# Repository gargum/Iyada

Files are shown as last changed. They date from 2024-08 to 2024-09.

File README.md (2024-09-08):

# Iyada

Iyada

*The Iyada is a keyboard, mouse, space mouse, and a gamepad in one unit*

* Keyboard Maintainer: [Gareth Gummow](https://github.com/gargum)
* Demonstration: [Iyada Dual Analogue Gameplay](https://imgur.com/gallery/iyada-simple-demos-vVryoOj)
* Recommended Keycaps: [KLP Lamé](https://github.com/braindefender/KLP-Lame-Keycaps)

This device is powered by QMK Firmware running on two RP2040 Microcontrollers.

To flash the firmware for it, simply copy the kiraibuilds/iyada directory to the ~/qmk_firmware/keyboards locally on your machine before following one of the make examples included in the appropriate Readme file.

To learn how to set up QMK locally on your machine, see the [build environment setup](https://docs.qmk.fm/#/getting_started_build_tools) and the [make instructions](https://docs.qmk.fm/#/getting_started_make_guide). 

Brand new to QMK? Start with the [Complete Newbs Guide](https://docs.qmk.fm/#/newbs)

## Features

* **Simultaneous Choc/MX Hotswap Compatibility**: The Iyada is simultaneously MX and Choc hotswap compatible. This means one can use any combination of Choc and MX switches or switch between them without having to reflash the firmware!
* **OLED Screens**: The Iyada is equipped with a 32x128 OLED screenn on each side. The lefthand OLED tells the user which layer is currently active, and the righthand OLED displays a fun, unobtrusive animation!
* **Four Encoders**: The Iyada is equipped with a rotary encoder and a scroll encoder on each side of the keyboard! By default, these are used for the purposes of web navigation and media playback.
* **Dual Pointers**: The Iyada is equipped with a Cirque Pinnacle trackpad on each side! By default, these can be used for mouse cursor movement. However, they are also configured to function as dual analogue sticks in video games!
* **RGB Lighting**: The baseplate of the Iyada comes equipped with LEDs, allowing for RGB animations and simple backlighting should the user so desire!
* **Haptic Feedback**: The Iyada is equipped with a DRV2605L on each half, allowing for haptic feedback that informs the user that a layer shift key has been pressed!
* **Audio Feedback**: The Iyada is equipeed with a small piezoelectric speaker on each side that relies on hardware-driven PWM to produce sound! By default, this allows the user to make the Iyada produce an audible sound whenever a key is pressed.
* **Power Boosting**: The Iyada is equipped with a TP4056 and a lithium polymer battery on each side! This allows one to provide extra power, thereby ensuring features like RGB and Haptics are always working as expected, no matter the configuration!
* **Advanced Autocorrect**: QMK includes the ability to define custom dictionaries for use with the [Autocorrect feature](https://docs.qmk.fm/features/autocorrect). As part of the Iyada project, the largest ever such dictionary has been created, compiled, and added for use with this, or any other piece of hardware that utilises QMK firmware!
* **Dual Analogue Support**: The Iyada natively supports virtual dual analogue sticks. This means, using software such as a video game emulator, one is able to map each Cirque Pinnacle trackpad to its own
separate analogue stick. The first version of full Cirque joystick emulation has already been implemented and is ready for use. Fully polished digital joystick emulation is still production!

## Additional Information

* **Cirque Sizing**: Although 40mm Cirque trackpads are recommended, one may use any size that one so desires. 40mm Cirque trackpads are used only because they are popularly considered to be the most comfortable variety. The only issue associated with using a smaller Cirque is that it may not be possible to attach these Cirques to the Iyada Cirque holders perfectly centred.
* **Cirque Holder**: UV resin is used to attach a Cirque to the Iyada Cirque holder. All 40mm Cirques have been confirmed to be able to attach to the standard Cirque holder regardless of the type of overlay it comes with. To attach a Cirque to the Iyada Cirque holder, it is recommended that one first attaches the Cirque holder to the Iyada top PCB using a heat-set insert and M2.2 screw, then connects the Cirque to the Iyada top PCB, before using something like hot glue or tape to test what position and orientation is most comfortable for use. After one is happy with the position and orientation, and after one is sure the Cirque has been connected to the Iyada top PCB properly, a very small amount of UV resin can then be used to permanently secure the trackpad to its holder. After this, the hot glue or tape may be removed. 
* **Curved Overlay**: All features including secondary click functions and scrolling functions work with the curved overlay, however the attenuation in config.h must be set to its maximum value of 1 for this to work consistently. It does still technically work if the attenuation is set to a value of 2, but in testing was reported as being frustrating to use.
* **Cirque Attenuation**: If one is not using the curved overlay, setting the attenuation in config.h to 3 or 4 generally works best. If one does have curved overlays on one's Cirque trackpads, then setting the attenuation to 1 or 2 generally works best.
* **Cirque Positioning**: It is recommended to mount each Cirque trackpad to the keyboard such that it is angled away from the MCU by an angle of between 20 degrees and 40 degrees. Mounting the Cirques perfectly straight tends to make it more difficult for one to use one's thumbs to control mouse pointing.
* **Cirque Conflicts**: It is worth noting that using the Steno and/or Joystick functionality may cause the Cirques to become less accurate, more prone to drifting, and overall more painful to use.
* **Cirque Problems**: If a Cirque trackpad is only partially connected, then the mouse pointer should jitter erratically when one attempts to use it. If SDA or SCL are not connected properly at all, then the Cirque trackpad will only be able to move in the X direction or in the Y direction but not both. If there is jittering in the X direction but not the Y direction, or vice versa, then either SDA or SCL is partially connected while the other is fully connected. If the Cirque drops user input periodically when the attenuation is set to 1, almost like stuttering or lagging, then 5V or GND are not properly connected. If the Cirque does not respond at all despite the correct solder jumpers being closed, then either that half is not receiving sufficient power, or the Cirque is not properly connected. To resolve every single one of these problems, use 3.3V Cirques, reconnect/resolder the Cirques, add the battery/charging accessories, and use either WS2812B-2020 LEDs or no LEDs at all before testing again. In case one simply removes a pad or trace by accident while adding a Cirque trackpad, each half of the keyboard has 3 places where it is possible to solder a Cirque alongside 2 places where an FPC connecter for a Cirque can be added. If none of this works, disconnect any LEDs and try using the Cirque. If it suddenly works fine, the problem was insufficient power. If nothing changes, the problem is the connection between the Cirque and the PCB.
* **Haptic Compatibility**: The Iyada is designed to support all haptic feedback drivers that are compatible with QMK. By default, it is configured to use the DRV2605L, however the Iyada is also natively compatible with solenoid drivers if one would prefer to use that instead.
* **Audio**: The Iyada natively supports the use of piezo speakers for the purposes of audio feedback. Simply hand-wire one's speaker to the appropriately on each half of the Iyada in order to utilise this feature.
* **SPI Peripherals**: The Iyada supports direct control of SPI-based peripherals, including Cirque trackpads that have been configured to communicate via SPI. If one wants to use any such peripheral, simply hand-wire the appropriate connections the corresponding 4 pins located on the bottom of the MCU.
* **Power Draw**: If one uses two 5V Cirque trackpads in tandem with WS2812B-5050 LEDs, the battery and charging accessories are required to provide all components with sufficient power simultaneously. Neglecting to do so when using this configuration will result in the 5V Cirque present on the secondary half of the keyboard to become non-responsive. Even with the additional battery and charging accessories, it is possible that there will still be insufficient power if one is using an Iyada with two 5V Cirque trackpads, WS2812B-5050 LEDs, and additional non-standard peripherals connected via an SPI to I2C bus-bridge such as the SC18IS604.
* **Battery Connections**: The Iyada natively supports the use of a lipo battery on each half to help power more energy-intensive configurations. Simply solder the battery wires to the TP4056 units on each half, and position the battery so as to not block any of the Iyada's LEDs.

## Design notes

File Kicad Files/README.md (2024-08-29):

# Iyada PCB

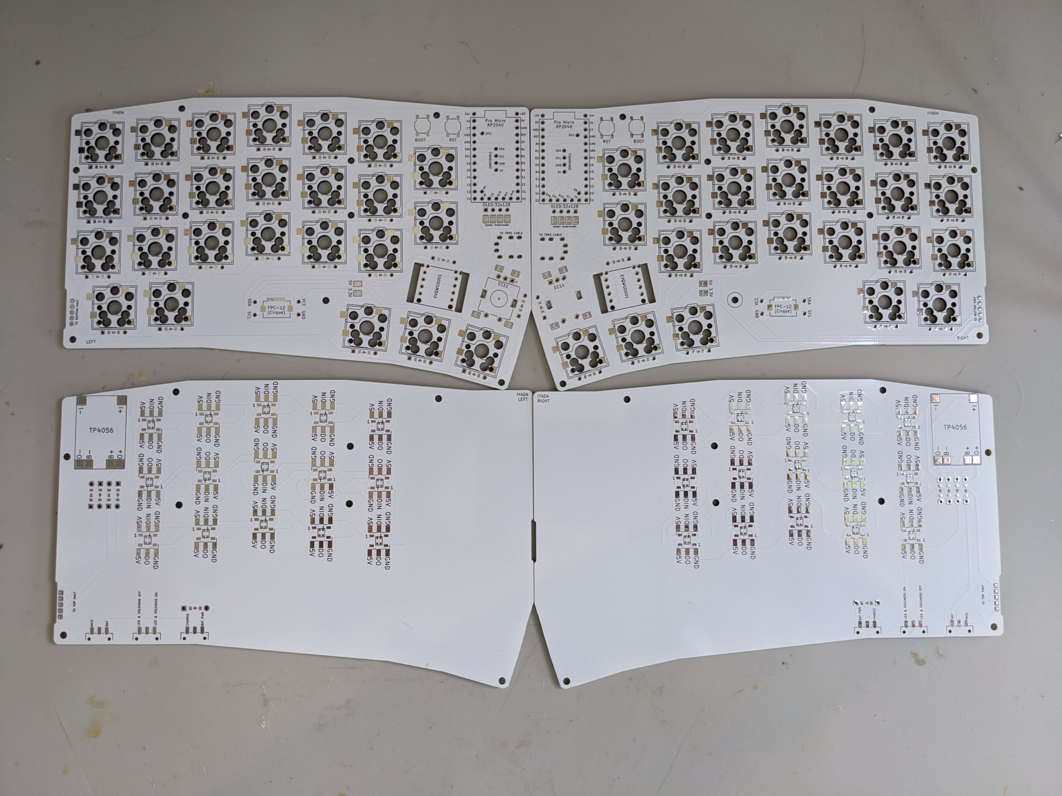
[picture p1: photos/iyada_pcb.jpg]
Iyada


*The Iyada comes in four parts - Top Left, Bottom Left, Top Right, and Bottom Right*

All PCBs used are reversible. This means a bottom PCB will function as both a bottom left and as a bottom right half, while a top PCB will function as both a top left and top right half.

## PCB Fabrication

The iyada_top and iyada_bottom directories each contain a .zip file, iyada_top.zip and iyada_bottom.zip respectively.

To fabricate the Iyada, simply take these .zip files, go to a website such as [JLCPCB](jlcpcb.com/) or [PCBWay](pcbway.com/), and upload them when prompted to provide a gerber file.

## Features

* **Reversible PCBs**: As previously mentioned, all PCBs are reversible, so only the top PCB functions as the top half of both sides, and the bottom PCB functions as the bottom half of both sides.
* **Simultaneous Choc & MX Hotswap Support**: Each key simultaneously accomodates Choc and MX hotswaps. This is to allow every key to accept a low-profile Choc switch, or a standard MX switch, without the need to resolder anything or reflash any firmware.
* **Two Rotary Encoders**: Each top PCB has a reversible slot for either an EC11 or EC12 rotary encoder, complete with intact click functionality!
* **Two Scroll Encoders**: Each top PCB has a reversible slot for a EVQWGD001 scroll encoder, also complete with intact click functionality!
* **Support for Multiple Sizes of LED**: The bottom PCB is designed to accomodate WS2812 RGB LEDs in multiple sizes, including WS2812 RGB LEDs cut from RGB LED strips!
* **TP4056 Slot**: Features like large LEDs and haptic feedback can take quite a lot of power. That's why the bottom PCB has a dedicated slot for a TP4056, which is used to safely provide more than enough additional electricity!

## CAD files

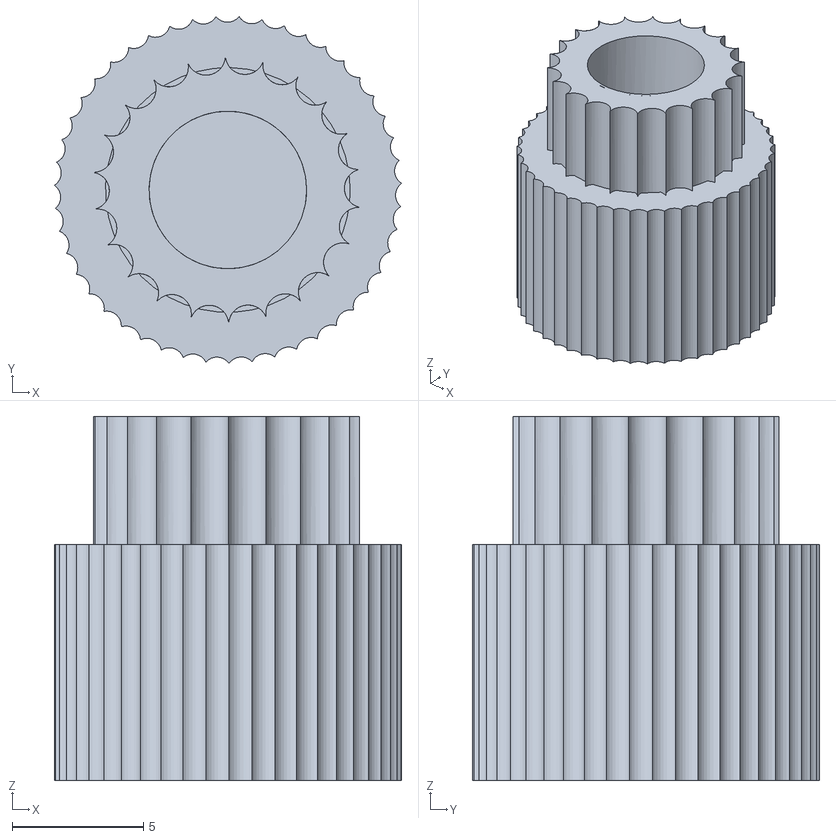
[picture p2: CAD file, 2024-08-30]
3D Print Files/Iyada - Encoder Knob - EC12.stl
13.2 x 13.2 x 13.9

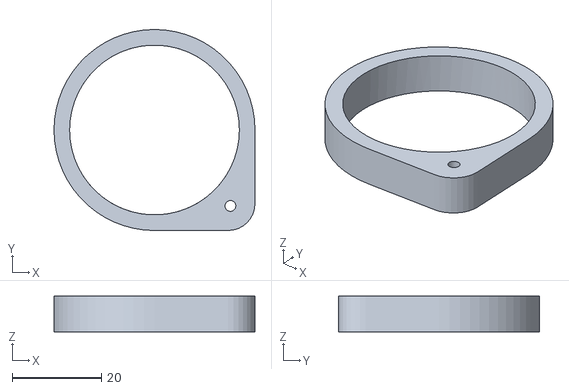
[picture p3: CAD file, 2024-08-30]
3D Print Files/Iyada - Cirque Holder.stl
45.0 x 45.0 x 8.00

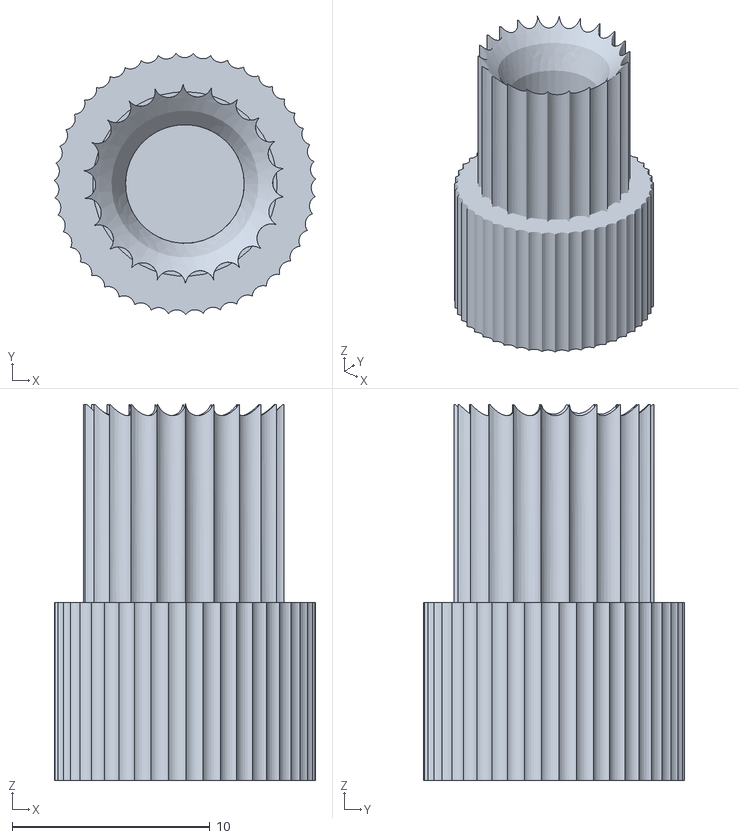
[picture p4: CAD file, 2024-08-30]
3D Print Files/Iyada - Encoder Knob - EC11.stl
13.2 x 13.2 x 19.0

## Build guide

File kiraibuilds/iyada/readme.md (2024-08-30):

# Iyada

Iyada (https://i.imgur.com/hbfquj2.mp4)

*The Iyada is a keyboard, mouse, space mouse, and a gamepad in one unit*

* Keyboard Maintainer: [Gareth Gummow](https://github.com/gargum)
* Hardware Supported: *2 Iyada top PCBs, 2 Iyada bottom PCBs, 2 Iyada base plates, 2 Iyada mounting rings, 2 Iyada Cirque holders, 2 RP2040 Pro Micro microcontrollers, 2 EC12 low profile rotary encoders, 2 EVQWGD001 scroll encoders, 2 OLEDs (32x128), 2 Cirque Pinnacle trackpads (40mm / TM040040 is recommended), 2 FPC 12-pin cables, 2 FPC reverse side solder-mount connectors, 100 Hotswap sockets (50 Choc & 50 MX, or 50 Choc & 50 Gateron), 30 WS2812B LEDs (WS2812B-2020 is recommended), 2 DRV2605L haptic drivers, 2 Haptic motors, 2 TP4056 lipo chargers, 2 lipo batteries, 6 SPDT switches, 2 TRRS connectors, 1 TRRS cable, 62 Diodes (62 1N4148 or 62 LL4148), 34 screws (M2.2), 2 heat-set inserts (M2.2), 16 M.2 SSD standoffs (All 16 must be the same height), Wires (30 Gauge), Solder (paste and/or wire), UV resin or hot glue or double-sided tape*
* Hardware Availability: [AliExpress](https://aliexpress.com), [Mouser](https://mouser.com), [DigiKey](https://digikey.com), [JLCPCB](https://jlcpcb.com), [PCBWay](https://pcbway.com)

Make example for this keyboard (after setting up your build environment):

    make kiraibuilds/iyada:default

Alternative make example for this keyboard using QMK:

    qmk compile -kb kiraibuilds/iyada -km joystick

Flashing example for this keyboard using QMK:

    qmk flash -kb kiraibuilds/iyada -km advanced

See the [build environment setup](https://docs.qmk.fm/#/getting_started_build_tools) and the [make instructions](https://docs.qmk.fm/#/getting_started_make_guide) for more information. 

Brand new to QMK? Start with the [Complete Newbs Guide](https://docs.qmk.fm/#/newbs)

## Bootloader

One can enter the bootloader of each keyboard half separately if one so chooses. This is necessary when flashing a newly constructed Iyada for the first time, and when one wishes to alter the default behaviours of the RGB LEDs.

One may also use a TRRS cable to connect both halves, before entering the bootloader on the master half alone. Flashing both halves simultaneously in this fashion is convenient when one is simply flashing a new keymap onto a pre-existing Iyada without making any other changes.

One is able to enter the bootloader in 5 ways:

* **Bootloader button**: First, unplug the Iyada from one's computer. Then, press and hold the button labelled 'Boot' on the front of the PCB, and keep it held down as one plugs the Iyada into the computer once more. This should cause the Iyada to enter the bootloader.
* **Reset button**: Simply double-tap the button labelled 'reset' on the front of the PCB. This should cause the Iyada to enter the bootloader.
* **Paperclip reset**: Take a screwdriver or paperclip, then use it to connect the RST and GND pins on the microcontroller. Please be careful, as one can accidentally short the MCU. By quickly doing this twice in a row, one is able to enter the bootloader using the reset button method without actually pressing the physical reset button.
* **Bootmagic reset**: Bootmagic is enabled by default. With Bootmagic, one can hold the top right key on the right half of the keyboard and plug it in. If using the left half by itself, or if holding the top right key on the right half of the board simply is not working, then instead hold the top left key on the left half of the keyboard.
* **Keycode in layout**: If one has included the keycode `QK_BOOT` somewhere in a custom keymap, then triggering it will enter the bootloader. This is unavailable on the default keymap.

## Additional Information

* **Cirque Sizing**: Although 40mm Cirque trackpads are recommended, one may use any size that one so desires. 40mm Cirque trackpads are used only because they are popularly considered to be the most comfortable variety. The only issue associated with using a smaller Cirque is that it may not be possible to attach these Cirques to the Iyada Cirque holders perfectly centred.
* **Cirque Holder**: UV resin is used to attach a Cirque to the Iyada Cirque holder. All 40mm Cirques have been confirmed to be able to attach to the standard Cirque holder regardless of the type of overlay it comes with. To attach a Cirque to the Iyada Cirque holder, it is recommended that one first attaches the Cirque holder to the Iyada top PCB using a heat-set insert and M2.2 screw, then connects the Cirque to the Iyada top PCB, before using something like hot glue or tape to test what position and orientation is most comfortable for use. After one is happy with the position and orientation, and after one is sure the Cirque has been connected to the Iyada top PCB properly, a very small amount of UV resin can then be used to permanently secure the trackpad to its holder. After this, the hot glue or tape may be removed. 
* **Curved Overlay**: All features including secondary click functions and scrolling functions work with the curved overlay, however the attenuation in config.h must be set to its maximum value of 1 for this to work consistently. It does still technically work if the attenuation is set to a value of 2, but in testing was reported as being frustrating to use.
* **Cirque Attenuation**: If one is not using the curved overlay, setting the attenuation in config.h to 3 or 4 generally works best. If one does have curved overlays on one's Cirque trackpads, then setting the attenuation to 1 or 2 generally works best.
* **Cirque Positioning**: It is recommended to mount each Cirque trackpad to the keyboard such that it is angled away from the MCU by an angle of between 20 degrees and 40 degrees. Mounting the Cirques perfectly straight tends to make it more difficult for one to use one's thumbs to control mouse pointing.
* **Cirque Conflicts**: It is worth noting that using the Steno and/or Joystick functionality may cause the Cirques to become less accurate, more prone to drifting, and overall more painful to use.
* **Cirque Problems**: If a Cirque trackpad is only partially connected, then the mouse pointer should jitter erratically when one attempts to use it. If SDA or SCL are not connected properly at all, then the Cirque trackpad will only be able to move in the X direction or in the Y direction but not both. If there is jittering in the X direction but not the Y direction, or vice versa, then either SDA or SCL is partially connected while the other is fully connected. If the Cirque drops user input periodically when the attenuation is set to 1, almost like stuttering or lagging, then 5V or GND are not properly connected. If the Cirque does not respond at all despite the correct solder jumpers being closed, then either that half is not receiving sufficient power, or the Cirque is not properly connected. To resolve every single one of these problems, use 3.3V Cirques, reconnect/resolder the Cirques, add the battery/charging accessories, and use either WS2812B-2020 LEDs or no LEDs at all before testing again. In case one simply removes a pad or trace by accident while adding a Cirque trackpad, each half of the keyboard has 3 places where it is possible to solder a Cirque alongside 2 places where an FPC connecter for a Cirque can be added. If none of this works, disconnect any LEDs and try using the Cirque. If it suddenly works fine, the problem was insufficient power. If nothing changes, the problem is the connection between the Cirque and the PCB.
* **Mounting Compatibility**: The internal tenting puck system is primarily for the purposes of attaching the Iyada to either a tripod, or of making it easier to secure the Iyada to an office chair. As the name implies, This also makes it possible to simply tent one's Iyada.
* **Haptic Compatibility**: The Iyada is designed to support all haptic feedback drivers that are compatible with QMK. By default, it is configured to use the DRV2605L, however the Iyada is also natively compatible with solenoid drivers if one would prefer to use that instead.
* **Audio**: The Iyada natively supports the use of piezo speakers for the purposes of audio feedback. Simply hand-wire one's speaker to the appropriately on each half of the Iyada in order to utilise this feature.
* **SPI Peripherals**: The Iyada supports direct control of SPI-based peripherals, including Cirque trackpads that have been configured to communicate via SPI. If one wants to use any such peripheral, simply hand-wire the appropriate connections the corresponding 4 pins located on the bottom of the MCU.
* **Power Draw**: If one uses two 5V Cirque trackpads in tandem with WS2812B-5050 LEDs, the battery and charging accessories are required to provide all components with sufficient power simultaneously. Neglecting to do so when using this configuration will result in the 5V Cirque present on the secondary half of the keyboard to become non-responsive. Even with the additional battery and charging accessories, it is possible that there will still be insufficient power if one is using an Iyada with two 5V Cirque trackpads, WS2812B-5050 LEDs, and additional non-standard peripherals connected via an SPI to I2C bus-bridge such as the SC18IS604.
* **Battery Connections**: The Iyada natively supports the use of a lipo battery on each half to help power more energy-intensive configurations. Simply solder the battery wires to the TP4056 units on each half, and position the battery so as to not block any of the Iyada's LEDs.
* **Dual Analogue Support**: The Iyada natively supports virtual dual analogue sticks. This means, using software such as a video game emulator, one is able to map each Cirque Pinnacle trackpad to its own
separate analogue stick for use in modern games. By default, flicking or swiping in a direction will toggle that direction, and tapping will reset it. This is to allow those with RSI or arthritis that prevents
one from holding down a standard analogue stick to use a dual analogue input method. As a side-effect, this method also frees up one's thumbs, better allowing one to use gamepad buttons mapped to the thumb cluster.

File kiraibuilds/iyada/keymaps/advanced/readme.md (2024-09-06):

# Advanced Iyada Layout - Introduction

The advanced layout exists to showcase as many of the existing features
of the Iyada as possible, while at the same time still remaining accessible
to those who are new to QMK. Learning this keymap should help beginners 
become acquainted with concepts including Layers, Combos, and Tap Dance, 
without being too confusing or overwhelming for novices.

Each half of the keyboard has a small OLED screen. These screens are 
there to provide information to the user regarding the current state of 
the keyboard, including which layer the keyboard is currently in, and even
whether problems with keyboard output are being caused by one's system being
unresponsive, or whether the problem is instead to do with the keyboard.

The primary layer, labelled 'main' on the secondary OLED display, outputs
letters using a standard QWERTY keymap.

The secondary layer, labelled 'symbol' on the secondary OLED display, allows
the user to press the Function keys F1-F12, the digits 0-9, and all shifted
variants of the ten digits such as the exclamation point and the dollar sign.
To enter this layer, simply press the corresponding Layer shift key located on
the lefthand thumb cluster.

The third layer, labelled 'mouse' on the secondary OLED display, allows the
user to control mouse movements, more easily reach arrow keys, and even change 
keyboard settings. Available settings on this layer include changing the behaviour 
of the LEDs, changing the behaviour of the haptic feedback module, and adjusting 
one's mouse sensitivity. To enter this settings layer, simply press the corresponding
Layer shift key located on the righthand thumb cluster.

On each half of the keyboard are a rotary encoder and a scroll encoder. 

On any layer, the lefthand rotary encoder can be turned to turn the system 
volume up or down. Pressing down on the lefthand rotary encoder will mute and 
unmute the system.

On any layer, the righthand rotary encoder can be turned to go to the next or
to the previous tab in Chromium-based web browsers like Chrome and Vivaldi. 
Pressing down on the righthand rotary encoder will pause or unpause media.

On any layer, the lefthand scroll encoder can be used to scroll up and down,
just as one would do with a standard mouse wheel. Pressing down on this 
scroll encoder will trigger the back button on any web browser, assisting
with web navigation.

On any layer, the righthand scroll encoder can be used to scroll side to side,
which may come in handy for some applications. Pressing down on this scroll
encoder will trigger the forward button on any web browser, again assisting
with web navigation.

Pressing both Layer shift keys simultaneously will toggle a fourth layer,
labelled 'Game' on the secondary OLED display. This layer transforms the
Iyada into a gamepad, with each Cirque Pinnacle trackpad functioning as
its own analogue stick and the face buttons also being remapped appropriately
to gamepad buttons.

On each layer, the six thumb keys, the leftmost column of three keys, and the
rightmost column of three keys will always be the same, although they are
deactivated when one is using the Game layer.

The lefthand cluster of three thumb keys, in order from left to right, 
correspond to Space, Backspace, and Symbols layer key. These keys function
normally with the exception of the Backspace key, which registers as a normal
Backspace key when tapped but outputs Ctrl+Backspace when held down.

The righthand cluster of three thumb keys, in order from left to right,
correspond to the Mouse layer toggle, Enter, and Shift respectively. No
special functions have been mapped to the Enter or Shift key. In this keymap,
Shift corresponds to the Left Shift key, and Right Shift is entirely absent.

The key on the outer bottom corners of each keyboard half are called Space
Cadet keys. When held, they correspond to the Ctrl key. When tapped, they
correspond to the left and right brackets, ( and ). 

The keys just above the Space Cadet keys function similarly. When held, they
correspond to the left and right Windows keys respectively. When tapped, the
lefthand key corresponds to the Delete key, when the righthand key outputs
the apostrophe key, with the appropriate behaviour when Shift is also held.

Finally, at the top left and top right corners of the keyboard are keys with
three different functions known as Tap Dance keys. 
When the topmost leftmost key is tapped, it outputs the Tab key.
When this key is held, it outputs the Left Alt key.
When this key is quickly double-tapped, it outputs the Escape key.

When the topmost rightmost key is tapped, it outputs a Backslash.
When this key is held, it outputs the Right Alt key.
When this key is quickly double-tapped, it outputs the Grave key.

This layout is recommended for those who have not previously owned a custom
mechanical keyboard, and for those who have not previously used a keyboard
that includes a built-in trackball or touchpad.

# Advanced Iyada Layout - Diagrams

<tt>

                                  MAIN LAYER

    ,---,---,---,---,---,---,                          ,---,---,---,---,---,---,
    |ESC| Q | W | E | R | T |---,                  ,---| Y | U | I | O | P | \ |
    '---'---'---'---'---'---| [ |                  | ] |---'---'---'---'---'---'
    |DEL| A | S | D | F | G '---'                  '---' H | J | K | L | ; | ' |
    '---'---'---'---'---'---| - |                  | = |---'---'---'---'---'---'
    |CTL| Z | X | C | V | B '---'                  '---' N | M | , | . | / |CTL|
    '---'---'---'---'---'---'                          '---'---'---'---'---'---'
      | V | < |            (EC1)(EC2)          (EC3)(EC4)            | > | ^ |
      '---'---'         ,---,---,---,          ,---,---,---,         '---'---'
                        |SPC|BCK|LSY|          |LMO|ENT|SFT|
                        '---'---'---'          '---'---'---'

                                     SYMBOL LAYER

    ,---,---,---,---,---,---,                          ,---,---,---,---,---,---,
    |ESC|F1 |F2 |F3 |F4 |F5 |---,                  ,---|F8 |F9 |F10|F11|F12| \ |
    '---'---'---'---'---'---|F6 |                  |F7 |---'---'---'---'---'---'
    |DEL| 1 | 2 | 3 | 4 | 5 '---'                  '---' 6 | 7 | 8 | 9 | 0 | ' |
    '---'---'---'---'---'---| - |                  | = |---'---'---'---'---'---'
    |CTL| ! | @ | # | $ | % '---'                  '---' ^ | & | * | . | ? |CTL|
    '---'---'---'---'---'---'                          '---'---'---'---'---'---'
      | V | < |            (EC1)(EC2)          (EC3)(EC4)            | > | ^ |
      '---'---'         ,---,---,---,          ,---,---,---,         '---'---'
                        |SPC|BCK|LMA|          |LMO|ENT|SFT|
                        '---'---'---'          '---'---'---'

                                     MOUSE LAYER

    ,---,---,---,---,---,---,                          ,---,---,---,---,---,---,
    |ESC|LVD|CWT|MSU|AST|REC|---,                  ,---|AC0|MS1| ^ |MS2|LVI| \ |
    '---'---'---'---'---'---|DTU|                  |DTD|---'---'---'---'---'---'
    |DEL|RGB|MSL|MSD|MSR|STP'---'                  '---'AC1| < | V | > |AUD| ' |
    '---'---'---'---'---'---| - |                  | = |---'---'---'---'---'---'
    |CTL|PRV|HDN|HTG|AON|PLY'---'                  '---'AC2|AOF|HRS|HUP|NXT|CTL|
    '---'---'---'---'---'---'                          '---'---'---'---'---'---'
      | V | < |            (EC1)(EC2)          (EC3)(EC4)            | > | ^ |
      '---'---'         ,---,---,---,          ,---,---,---,         '---'---'
                        |SPC|BCK|LPR|          |LPR|ENT|SFT|
                        '---'---'---'          '---'---'---'

                                     GAME LAYER

    ,---,---,---,---,---,---,                          ,---,---,---,---,---,---,
    |HOM|   |   |L2 |L1 |L3 |---,                  ,---|R3 |R1 |R2 |   |   |LPR|
    '---'---'---'---'---'---|SEL|                  |STA|---'---'---'---'---'---'
    |   |L1 |L2 |R2 |R1 |DUP'---'                  '---'DDN|CRO|CIR|SQU|TRI|   |
    '---'---'---'---'---'---|   |                  |   |---'---'---'---'---'---'
    |   |PRV|HDN|HTG|   |DLT'---'                  '---'DRT|   |HRS|HUP|NXT|   |
    '---'---'---'---'---'---'                          '---'---'---'---'---'---'
      |SEL|SEL|            (EC1)(EC2)          (EC3)(EC4)            |STA|STA|
      '---'---'         ,---,---,---,          ,---,---,---,         '---'---'
                        |L1 |L2 |L3 |          |R3 |R2 |R1 |
                        '---'---'---'          '---'---'---'

                                     STENO LAYER

    ,---,---,---,---,---,---,                          ,---,---,---,---,---,---,
    | 1 | 2 | 3 | 4 | 5 | 6 |---,                  ,---| 7 | 8 | 9 | A | B | C |
    '---'---'---'---'---'---|RES|                  |RES|---'---'---'---'---'---'
    |FN1| S | T | P | H | * '---'                  '---' * | F | P | L | T | D |
    '---'---'---'---'---'---|FN1|                  |FN2|---'---'---'---'---'---'
    |FN2| S | K | W | R | * '---'                  '---' * | R | B | G | S | Z |
    '---'---'---'---'---'---'                          '---'---'---'---'---'---'
      | * | * |            (EC1)(EC2)          (EC3)(EC4)            | * | * |
      '---'---'         ,---,---,---,          ,---,---,---,         '---'---'
                        | A | O | * |          | * | E | U |
                        '---'---'---'          '---'---'---'

   ,---,  - Tap:               Tab key
   |ESC|  - Hold:              Left Alt key
   '---'  - Double-tap:        Escape key
 
   ,---,  - Tap:               Delete key
   |DEL|  - Hold:              Left GUI/OS key
   '---'

   ,---,  - Tap (Left Side):   Left parenthesis - (
   |CTL|  - Hold (Left Side):  Left Control key
   '---'

   ,---,  - Tap:               Backslash key - \
   | \ |  - Hold:              Right Alt key
   '---'  - Double-tap:        Grave key - '

   ,---,  - Tap:               Apostrophe/Quote key - '
   | ' |  - Hold:              Right GUI/OS key
   '---'

   ,---,  - Tap (Right Side):  Right parenthesis - )
   |CTL|  - Hold (Right Side): Right Control key
   '---'

   ,---,  - Tap:               Backspace key
   |BCK|  - Hold:              Control + Backspace key
   '---'

   ,---,  - Tap:               Browser - Back Button
   |EC1|  - Scroll Up:         Mouse Wheel - Up
   '---'  - Scroll Down:       Mouse Wheel - Down

   ,---,  - Tap:               Mute / Unmute
   |EC2|  - Scroll Left:       Volume Down
   '---'  - Scroll Right:      Volume Up

   ,---,  - Tap:               Media - Play / Pause
   |EC3|  - Scroll Left:       Browser - Tab Left
   '---'  - Scroll Right:      Browser - Tab Right

   ,---,  - Tap:               Browser - Forward Button
   |EC4|  - Scroll Up:         Mouse Wheel - Right
   '---'  - Scroll Down:       Mouse Wheel - Left

   ,---,  - Tap:               Enter Symbol Layer - Toggle on/off
   |LSY|  - Hold:              Enter Symbol Layer - Only while held
   '---'

   ,---,  - Tap:               Enter Mouse Layer - Toggle on/off
   |LMO|  - Hold:              Enter Mouse Layer - Only while held
   '---'

   ,---,  - Tap:               Enter Main Layer - Toggle on/off
   |LMA|  - Hold:              Enter Main Layer - Only while held
   '---'

   ,---,  - Tap:               Enter Previous Layer - Toggle
   |LPR|  - Hold:              Enter Previous Layer - Only while held
   '---'

   ,---, 
   |PRV|  - Tap or Hold:       Haptic feedback modules - Previous waveform
   '---'

   ,---, 
   |HDN|  - Tap or Hold:       Haptic feedback modules - Decrease strength
   '---'

   ,---, 
   |HTG|  - Tap or Hold:       Haptic feedback modules - Toggle on/off
   '---'

   ,---, 
   |HRS|  - Tap or Hold:       Haptic feedback modules - Reset waveform and strength to default
   '---'

   ,---, 
   |HUP|  - Tap or Hold:       Haptic feedback modules - Increase strength
   '---'

   ,---,
   |NXT|  - Tap or Hold:       Haptic feedback modules - Next waveform
   '---'

   ,---, 
   |RGB|  - Tap or Hold:       LED Lighting - Toggle on/off
   '---'

   ,---, 
   |LVI|  - Tap or Hold:       LED Value (Brightness) - Increase value
   '---'

   ,---,
   |LVD|  - Tap or Hold:       LED Value (Brightness) - Decrease value
   '---'

   ,---, 
   |DTU|  - Tap or Hold:       Dynamic Tapping Term - Increase value - This feature is disabled by default
   '---'

   ,---, 
   |DTD|  - Tap or Hold:       Dynamic Tapping Term - Decrease value - This feature is disabled by default
   '---'

   ,---, 
   |CWT|  - Tap or Hold:       Caps Word - Toggle on/off
   '---'

   ,---, 
   |AON|  - Tap or Hold:       Autocorrect - Turn on
   '---'

   ,---, 
   |AOF|  - Tap or Hold:       Autocorrect - Turn off
   '---'

   ,---, 
   |AUD|  - Tap or Hold:       PWM speakers - Toggle on/off
   '---'

   ,---, 
   |REC|  - Tap or Hold:       Begin recording a Dynamic Macro - This feature is disabled by default
   '---'

   ,---, 
   |STP|  - Tap or Hold:       Stop recording a Dynamic Macro - This feature is disabled by default
   '---'

   ,---,
   |PLY|  - Tap or Hold:       Play one's previously recorded Dynamic Macro - This feature is disabled by default
   '---'

   ,---, 
   |AC0|  - Tap or Hold:       Adjust the mouse acceleration or DPI to its lowest setting
   '---'

   ,---, 
   |AC1|  - Tap or Hold:       Adjust the mouse acceleration or DPI to its medium setting
   '---'

   ,---, 
   |AC2|  - Tap or Hold:       Adjust the mouse acceleration or DPI to its highest setting
   '---'

   ,---,
   |MS1|  - Tap or Hold:       Left-click, also known as Mouse Button 1
   '---'

   ,---,
   |MS2|  - Tap or Hold:       Right-click, also known as Mouse Button 2
   '---'

   ,---,
   |MSD|  - Tap or Hold:       Move the mouse cursor downwards
   '---'

   ,---,
   |MSU|  - Tap or Hold:       Move the mouse cursor upwards
   '---'

   ,---,
   |MSL|  - Tap or Hold:       Move the mouse cursor to the left
   '---'

   ,---,
   |MSR|  - Tap or Hold:       Move the mouse cursor to the right
   '---'

   ,---,
   |STA|  - Tap or Hold:       Press the Start button - Joystick
   '---'

   ,---,
   |SEL|  - Tap or Hold:       Press the Select button - Joystick
   '---'

   ,---,
   |HOM|  - Tap or Hold:       Press the Home button - Joystick
   '---'

   ,---,
   |DUP|  - Tap or Hold:       Press Up on the D-Pad - Joystick
   '---'

   ,---,
   |DDN|  - Tap or Hold:       Press Down on the D-Pad - Joystick
   '---'

   ,---,
   |DLT|  - Tap or Hold:       Press Left on the D-Pad - Joystick
   '---'

   ,---,
   |DRT|  - Tap or Hold:       Press Right on the D-Pad - Joystick
   '---'

   ,---,
   |CRO|  - Tap or Hold:       Press the Cross or 'X' button - Joystick
   '---'

   ,---,
   |CIR|  - Tap or Hold:       Press the Circle or 'O' button - Joystick
   '---'

   ,---,
   |SQU|  - Tap or Hold:       Press the Square button - Joystick
   '---'

   ,---,
   |TRI|  - Tap or Hold:       Press the Triangle button - Joystick
   '---'

   ,---,
   |L1 |  - Tap or Hold:       Press the L1 button - Joystick
   '---'

   ,---,
   |L2 |  - Tap or Hold:       Press the L2 button - Joystick
   '---'

   ,---,
   |L3 |  - Tap or Hold:       Press the L3 button - Joystick
   '---'

   ,---,
   |R1 |  - Tap or Hold:       Press the R1 button - Joystick
   '---'

   ,---,
   |R2 |  - Tap or Hold:       Press the R2 button - Joystick
   '---'

   ,---,
   |R3 |  - Tap or Hold:       Press the R3 button - Joystick
   '---'

</tt>

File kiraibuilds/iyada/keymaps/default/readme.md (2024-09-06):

# Default Iyada Layout - Introduction

The default layout is designed to be as simple and accessible as
possible for as many people as possible.

While this keymap does utilise layers and Space Cadet, it does not 
utilise any other advanced feature of QMK including Combos, Tap Dance,
Custom Keycodes, Autocorrect, Autoshift, etc.

# Default Iyada Layout - Diagrams

<tt>

                                  MAIN LAYER

    ,---,---,---,---,---,---,                          ,---,---,---,---,---,---,
    |DEL| Q | W | E | R | T |---,                  ,---| Y | U | I | O | P | \ |
    '---'---'---'---'---'---| [ |                  | ] |---'---'---'---'---'---'
    |TAB| A | S | D | F | G '---'                  '---' H | J | K | L | ; | ' |
    '---'---'---'---'---'---| - |                  | = |---'---'---'---'---'---'
    |CTL| Z | X | C | V | B '---'                  '---' N | M | , | . | / |CTL|
    '---'---'---'---'---'---'                          '---'---'---'---'---'---'
      | V | < |                                                      | > | ^ |
      '---'---'         ,---,---,---,          ,---,---,---,         '---'---'
                        |SPC|BCK|LSY|          |LMO|ENT|SFT|
                        '---'---'---'          '---'---'---'

                                     SYMBOL LAYER

    ,---,---,---,---,---,---,                          ,---,---,---,---,---,---,
    |ESC|F1 |F2 |F3 |F4 |F5 |---,                  ,---|F8 |F9 |F10|F11|F12| ` |
    '---'---'---'---'---'---|F6 |                  |F7 |---'---'---'---'---'---'
    |GUI| 1 | 2 | 3 | 4 | 5 '---'                  '---' 6 | 7 | 8 | 9 | 0 |GUI|
    '---'---'---'---'---'---| - |                  | = |---'---'---'---'---'---'
    |ALT| ! | @ | # | $ | % '---'                  '---' ^ | & | * | . | ? |ALT|
    '---'---'---'---'---'---'                          '---'---'---'---'---'---'
      | V | < |                                                      | > | ^ |
      '---'---'         ,---,---,---,          ,---,---,---,         '---'---'
                        |SPC|BCK|LQW|          |LMO|ENT|SFT|
                        '---'---'---'          '---'---'---'

                                     MOUSE LAYER

    ,---,---,---,---,---,---,                          ,---,---,---,---,---,---,
    |EHL|LBD|MS2| ^ |MS1|AC0|---,                  ,---|AC0|MS1| ^ |MS2|LBI|EHR|
    '---'---'---'---'---'---|EHR|                  |EHL|---'---'---'---'---'---'
    |HOM|RGB| < | V | > |AC1'---'                  '---'AC1| < | V | > |AUD|END|
    '---'---'---'---'---'---|PSC|                  |INS|---'---'---'---'---'---'
    |PGD|PRV|HDN|HTG|LSD|AC2'---'                  '---'AC2|LSI|HRS|HUP|NXT|PGU|
    '---'---'---'---'---'---'                          '---'---'---'---'---'---'
      | V | < |                                                      | > | ^ |
      '---'---'         ,---,---,---,          ,---,---,---,         '---'---'
                        |SPC|BCK|LSY|          |LQW|ENT|SFT|
                        '---'---'---'          '---'---'---'

   ,---,  - Tap (Right Side):  Right parenthesis - )
   |CTL|  - Hold (Right Side): Right Control key
   '---'

   ,---,  - Tap (Left Side):   Left parenthesis - (
   |CTL|  - Hold (Left Side):  Left Control key
   '---'

   ,---, 
   |PSC|  - Tap or Hold:       Print Screen key
   '---'

   ,---, 
   |HOM|  - Tap or Hold:       Home key
   '---'

   ,---, 
   |END|  - Tap or Hold:       End key
   '---'
   
   ,---, 
   |LSY|  - Tap or Hold:       Symbol Layer Toggle
   '---'

   ,---, 
   |LMO|  - Tap or Hold:       Mouse Layer Toggle
   '---'
   
   ,---, 
   |LQW|  - Tap or Hold:       Main/QWERTY Layer Toggle
   '---'

   ,---, 
   |AC0|  - Tap or Hold:       Cirque Mouse Cursor Acceleration - Low
   '---'

   ,---, 
   |AC1|  - Tap or Hold:       Cirque Mouse Cursor Acceleration - Medium
   '---'

   ,---, 
   |AC2|  - Tap or Hold:       Cirque Mouse Cursor Acceleration - High
   '---'

   ,---, 
   |EHL|  - Tap or Hold:       Declare the Half that's Currently Plugged in to be the Left Half
   '---'

   ,---, 
   |EHR|  - Tap or Hold:       Declare the Half that's Currently Plugged in to be the Right Half
   '---'

   ,---, 
   |RGB|  - Tap or Hold:       RGB LED Toggle
   '---'

   ,---, 
   |AUD|  - Tap or Hold:       Audio Toggle
   '---'

   ,---, 
   |LBD|  - Tap or Hold:       RGB LED Brightness - Decrease
   '---'

   ,---, 
   |LBI|  - Tap or Hold:       RGB LED Brightness - Increase
   '---'

   ,---, 
   |LSD|  - Tap or Hold:       RGB LED Saturation - Decrease
   '---'

   ,---, 
   |LSI|  - Tap or Hold:       RGB LED Saturation - Increase
   '---'
   
   ,---, 
   |PRV|  - Tap or Hold:       Haptic feedback modules - Previous waveform
   '---'

   ,---, 
   |HDN|  - Tap or Hold:       Haptic feedback modules - Decrease strength
   '---'

   ,---, 
   |HTG|  - Tap or Hold:       Haptic feedback modules - Toggle on/off
   '---'

   ,---, 
   |HRS|  - Tap or Hold:       Haptic feedback modules - Reset waveform and strength to default
   '---'

   ,---, 
   |HUP|  - Tap or Hold:       Haptic feedback modules - Increase strength
   '---'

   ,---,
   |NXT|  - Tap or Hold:       Haptic feedback modules - Next waveform
   '---'
   
</tt>

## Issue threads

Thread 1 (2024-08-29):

Thumb cluster adjustment

gargum, 2024-08-29:
The current incline of the thumb cluster makes using the encoders with one's thumbs difficult unless one moves one's hands away from the home row. The incline of the thumb cluster must be made more steep to alleviate this.

Additionally, the spacings between the encoders and buttons on the thumb cluster is not consistent. The distances between the encoders and thumb cluster buttons must be reduced to make reaching the encoders easier, and the distances between the encoders and thumb cluster buttons must also be further adjusted to ensure distances are equal.

gargum, 2024-09-08:
The initial version of the Iyada Large PCB includes these changes. Testing to commence following a further polish of the Cirque Joystick code.

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

Closed 2024-09-08.

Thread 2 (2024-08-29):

Three additional buttons needed

gargum, 2024-08-29:
Currently, buttons like the escape key require double-tapping, which is incredibly RSI-unfriendly.

A cluster of three additional buttons is needed on the outer edges of the board such that the majority of the functions currently mapped to the same key can be placed onto their own individual buttons. Doing this would ensure double-tapping is never required in order to access keyboard functions.

gargum, 2024-09-08:
The initial version of the Iyada Large PCB includes these changes. Testing to commence following a further polish of the Cirque Joystick code.

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

Closed 2024-09-08.

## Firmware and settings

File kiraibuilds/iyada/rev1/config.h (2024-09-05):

/*
* This file is used to configure the default behaviours of the Iyada when given features like RGB and Audio are enabled.
*/

#pragma once

// for split keyboard initialization
    #define EE_HANDS
    #define SPLIT_LAYOUT
    #define SPLIT_USB_DETECT
    #define SPLIT_USB_TIMEOUT 2000
    #define SPLIT_USB_TIMEOUT_POLL 10
    #define SPLIT_ACTIVITY_ENABLE
    #define SPLIT_TRANSPORT_MIRROR
    #define SPLIT_LAYER_STATE_ENABLE
    #define SPLIT_MODS_ENABLE
    #define SPLIT_OLED_ENABLE
    #define SPLIT_HAPTIC_ENABLE
    #define SPLIT_POINTING_ENABLE
    #define SPLIT_LED_STATE_ENABLE
    #define SPLIT_WATCHDOG_ENABLE
    #define SPLIT_WATCHDOG_TIMEOUT 3000
    
// Tap Dance default behaviour settings
#ifdef TAP_DANCE_ENABLE
    #undef TAPPING_TERM
    #undef TAPPING_TOGGLE
    #define TAPPING_TERM 150
    #define TAPPING_TOGGLE 1
#endif

// Pointer (Cirque Pinnacle) initialization settings
#ifdef POINTING_DEVICE_ENABLE
    #define MOUSE_EXTENDED_REPORT
    #define POINTING_DEVICE_COMBINED
    #define POINTING_DEVICE_TASK_THROTTLE_MS 10
    #define CIRQUE_PINNACLE_DIAMETER_MM 40
    #define CIRQUE_PINNACLE_POSITION_MODE CIRQUE_PINNACLE_ABSOLUTE_MODE
    #define CIRQUE_PINNACLE_ATTENUATION EXTREG__TRACK_ADCCONFIG__ADC_ATTENUATE_4X
    #define CIRQUE_PINNACLE_TIMEOUT 20
    #define CIRQUE_PINNACLE_TAP_ENABLE
    #define CIRQUE_PINNACLE_CIRCULAR_SCROLL_ENABLE
#endif

// RGB initialization settings
#ifdef RGBLIGHT_ENABLE
    #define RGBLIGHT_LED_COUNT 30
    #define RGBLED_SPLIT { 15, 15 }
    #define RGBLIGHT_EFFECT_BREATHING
    #define RGBLIGHT_LIMIT_VAL 165
    #define RGBLIGHT_DEFAULT_VAL 130
    #define RGBLIGHT_DEFAULT_MODE RGBLIGHT_MODE_BREATHING
    #define RGBLIGHT_DEFAULT_SPD 3
#endif

// Haptic feedback initialization settings
#ifdef HAPTIC_ENABLE
    #define DRV2605L_FB_ERM_LRA 0
    #define DRV2605L_FB_BRAKEFACTOR 6
    #define DRV2605L_FB_LOOPGAIN 3
    #define DRV2605L_RATED_VOLTAGE 2.7
    #define DRV2605L_V_PEAK 5.1
// Haptic feedback behaviour settings - Vibrations
    #define DRV2605L_GREETING 82
    #define DRV2605L_DEFAULT_MODE 7
    #define NO_HAPTIC_ALPHA
    #define NO_HAPTIC_PUNCTUATION
    #define NO_HAPTIC_LOCKKEYS
    #define NO_HAPTIC_NAV
    #define NO_HAPTIC_NUMERIC
#endif

// Audio settings - Sound settings
#ifdef AUDIO_ENABLE
    #define AUDIO_CLICKY
    #define AUDIO_CLICKY_FREQ_DEFAULT 250
    #define AUDIO_CLICKY_FREQ_MIN 100
    #define AUDIO_CLICKY_FREQ_MAX 400
#endif

// Joystick settings - Axis definitions
#ifdef JOYSTICK_ENABLE
    #define JOYSTICK_AXIS_COUNT 4
    #define JOYSTICK_BUTTON_COUNT 17
#endif

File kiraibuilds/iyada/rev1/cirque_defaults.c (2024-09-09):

#include QMK_KEYBOARD_H
#include "keyboard.h"

//Including the joystick.h file only if joysticks are actually enabled
#if defined(JOYSTICK_ENABLE)
#   include "joystick.h"
#   endif

//Including the Cirque drivers. This is being used to poll the Absolute X and Absolute Y values.
//
//NOTE: Use <variable>.xValue,  <variable>.yValue,  <variable>.zValue, and  <variable>.touchDown to actually poll/manipulate the data sent by the Cirque(s).
#include "drivers/sensors/cirque_pinnacle.h"

//Defining 4 virtual joystick axes, but only if joysticks are actually enabled. 
//We will be mapping the data polled from the Cirques onto these 4 axes later on.
#if defined(JOYSTICK_ENABLE)
#   include "joystick.h"
joystick_config_t joystick_axes[JOYSTICK_AXIS_COUNT] = {
    JOYSTICK_AXIS_VIRTUAL, // 0 -  Left Stick, X
    JOYSTICK_AXIS_VIRTUAL, // 1 -  Left Stick, Y
    JOYSTICK_AXIS_VIRTUAL, // 2 - Right Stick, X
    JOYSTICK_AXIS_VIRTUAL  // 3 - Right Stick, Y
};
#   endif
//Layer maps: 
//
//Having your layers declared in a separate file makes it easier for several files to all employ layer-dependant behaviours.
//This is a non-standard feature I just made up, so it will only be included if the user decides to copy the idea.
#if __has_include( "layers.h" ) && defined(LAYER_MAP)
    #include "layers.h"
#endif

//Inverting the circular scroll function on the right-hand side:
//
//Circular scrolling starting from the side of a given Cirque that faces the opposite keyboard half is vertical scrolling,
//Circular scrolling starting from the outer side of a given Cirque is horizontal scrolling.
#if defined(CIRQUE_PINNACLE_CIRCULAR_SCROLL_ENABLE) && defined(POINTING_DEVICE_COMBINED)
void pointing_device_init_user(void) {
cirque_pinnacle_configure_circular_scroll(33, 16, 9102, 18, !is_keyboard_left());
};
#endif

//Cirque Joystick Modes:
//
//There are multiple ways one might want the pair of Cirque trackpads to behave.
//As such, two buttons (KC_CNCL and KC_SYRQ) alongside this integer are used to toggle between multiple Joystick Modes.
#ifdef JOYSTICK_ENABLE
uint8_t cirque_joystick_mode = 1;
#endif

//Cirque CPI Settings
//
//KC_ACL0, KC_ACL1, and KC_ACL2 do not normally affect the CPI/DPI of Cirque trackpads.
//This integer alongside the code that follows used the pointing_device_set_cpi_on_side function to change that!
uint8_t cirque_cpi_setting = 1;
bool process_record_user(uint16_t keycode, keyrecord_t *record) {
  switch (keycode) {
    case KC_ACL0:
      if (record->event.pressed) {
        pointing_device_set_cpi_on_side(false, 300);
        pointing_device_set_cpi_on_side(true, 300);
        cirque_cpi_setting = 0;
      }
      return false; // Skip all further processing of this key
    case KC_ACL1:
      if (record->event.pressed) {
        pointing_device_set_cpi_on_side(false, 600);
        pointing_device_set_cpi_on_side(true, 600);
        cirque_cpi_setting = 1;
      }
      return false; // Skip all further processing of this key
    case KC_ACL2:
      if (record->event.pressed) {
        pointing_device_set_cpi_on_side(false, 800);
        pointing_device_set_cpi_on_side(true, 800);
        cirque_cpi_setting = 2;

      }
      return false; // Skip all further processing of this key
//Joystick Mode Shifting
//
//This code simply checks whether KC_CNCL or KC_SYRQ have been pressed, and changes the Joystick Mode value accordingly.
#ifdef JOYSTICK_ENABLE
    case KC_SYRQ:
      if (record->event.pressed) {
      
        if(cirque_joystick_mode > 1){
            cirque_joystick_mode -= 1;
        }else if(cirque_joystick_mode == 1){
            cirque_joystick_mode = 3;
        }

      }
      return false; // Skip all further processing of this key
    case KC_CNCL:
      if (record->event.pressed) {
        
        if(cirque_joystick_mode < 3){
            cirque_joystick_mode += 1;
        }else if(cirque_joystick_mode == 3){
            cirque_joystick_mode = 1;
        }

      }
      return false; // Skip all further processing of this key
#endif
    default:
      return true; // Process all other keycodes normally
  }
}

// Pointers - Initialization
//
// This is the beginning of the Cirque & Cirque Joystick code block
#ifdef POINTING_DEVICE_COMBINED
report_mouse_t pointing_device_task_combined_kb(report_mouse_t left_report, report_mouse_t right_report) {

//Cirque Joystick Code - Mode 1 Code
//
//Mode 1 - Polling the Absolute X and Absolute Y values from one Cirque trackpad, while treating the other as a mouse
#ifdef JOYSTICK_ENABLE
if(cirque_joystick_mode == 1){

//The is_keyboard_left() function is used here because the cirque_pinnacle_read_data() function ONLY returns the data corresponding to the Master half's Cirque*
if(is_keyboard_left()){
//Left Stick Code
pinnacle_data_t left_joystick_set = cirque_pinnacle_read_data();

uint16_t xLeftTemp = ((left_joystick_set.xValue/8)-128);
uint16_t yLeftTemp = ((left_joystick_set.yValue/8)-128);

        if(left_joystick_set.touchDown!=0||left_joystick_set.zValue!=0){
            joystick_set_axis(0, +xLeftTemp);
            joystick_set_axis(1, +yLeftTemp);
        }
        

}else{
//Right Stick Code
pinnacle_data_t right_joystick_set = cirque_pinnacle_read_data();

uint16_t xRightTemp = ((right_joystick_set.xValue/8)-128);
uint16_t yRightTemp = ((right_joystick_set.yValue/8)-128);

        if(right_joystick_set.touchDown!=0||right_joystick_set.zValue!=0){
            joystick_set_axis(2, +xRightTemp);
            joystick_set_axis(3, +yRightTemp);
        }


}
//Cirque Joystick Code - Mode 2 Code
//
//Mode 2 - Swiping in a direction on a given Cirque holds the corresponding joystick in that direction, while tapping resets it.
} else if (cirque_joystick_mode == 2) {
    //Left Stick Code
    uint16_t LeftCirqueX  = joystick_read_axis(0)+left_report.x;
    uint16_t LeftCirqueY  = joystick_read_axis(1)+left_report.y;
        //Left Stick - X Axis
        if(left_report.x!=0){
            joystick_set_axis(0, LeftCirqueX);
        }
        //Left Stick - Y Axis
        if(left_report.y!=0){
            joystick_set_axis(1, LeftCirqueY);
        }
    //Right Stick Code   
    uint16_t RightCirqueX = joystick_read_axis(2)+right_report.x;
    uint16_t RightCirqueY = joystick_read_axis(3)+right_report.y;
        //Right Stick - X Axis
        if(right_report.x!=0){
            joystick_set_axis(2, RightCirqueX);
        }
        //Right Stick - Y Axis
        if(right_report.y!=0){
            joystick_set_axis(3, RightCirqueY);
        }
//Cirque Joystick Code - Mode 3 Code
//
//Mode 3 - Polling the Absolute X and Absolute Y values from one Cirque trackpad, while putting the other into Mode 2
} else if (cirque_joystick_mode == 3) {
    if(is_keyboard_left()){
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

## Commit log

2024-07-29 Added all PCB files
    Added all files associated with the Iyada PCB itself
    [iyada_scroll.kicad_pcb]
2024-07-29 Bottom half added
    Added all the PCB files for the bottom half of the Iyada
    [iyada_baseplate.kicad_pcb]
2024-07-29 Added files for the bottom half of the PCB
    [iyada_baseplate.kicad_pcb]
2024-07-29 Moved iyada_bottom directory
    iyada_bottom directory consists entirely of Kicad files, therefore it should be a subdirectory of Kicad Files, not its own separate folder.
    [iyada_baseplate.kicad_pcb]
2024-08-17 Delete iyada directory
    This directory is so outdated that it needs to be replaced entirely.
    [config.h, keymap.c]
2024-08-17 Delete Kicad Files directory
    This directory is so outdated that it needs to be replaced
    [iyada_baseplate.kicad_pcb, iyada_scroll.kicad_pcb]
2024-08-17 Replaced all Kicad Files
    Replaced all of the Kicad Files that were previously deleted for being too outdated
    [iyada_bottom-B_Cu.gbr, iyada_bottom-B_Mask.gbr, iyada_bottom-B_Paste.gbr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]
2024-08-23 Update mcuconf.h
    -Increased USB_MAX_POWER_CONSUMPTION without editing QMK itself in any way
    -Changed the pin for SPEAKER_SHUTDOWN ahead of future changes to the PCB
2024-08-24 Update mcuconf.h
    The pins for the encoders were backwards, so clockwise and counter-clockwise were inverted on every encoder.
    This is now fixed.
    [mcuconf.h]
2024-08-24 Delete keymaps/default directory
    This is no longer the default keymap. These files are now in keymaps/advanced.
    [keymap.c]
2024-08-25 Deleted keymaps directory
    This is deprecated and must be replaced
    [config.h, keymap.c]
2024-08-25 Added the new keymaps directory
    The previous keymaps directory was outdated.
    This new directory includes multiple new keymaps and has fewer bugs, including the removal of OLED behavioural bugs on some keymaps.
    [config.h, keymap.c]
2024-08-29 Fixed broken joystick button keycodes
2024-08-29 Fixing bug with steno combos on some power configurations
2024-08-29 Created README.md for the Kicad Files
2024-08-30 Added the 3D print files associated with the Iyada
    [Iyada - Cirque Holder.stl, Iyada - Encoder Knob.stl]
2024-08-30 Removing outdated 3D print file
    [Iyada - Cirque Holder.stl]
2024-08-30 Added the updated 3D print file
    [Iyada - Cirque Holder.stl]
2024-08-30 Deleted outdated Encoder Knob file
    [Iyada - Encoder Knob.stl]
2024-08-30 Replaced the outdated Encoder Knob files
    [Iyada - Encoder Knob - EC11.stl, Iyada - Encoder Knob - EC12.stl]
2024-09-02 Adding new features
    - Added auto-adjusting power draw
    - Added toggle for the default configurations
    - Layer maps
2024-09-02 Added support for auto-adjusting power draw
2024-09-02 Replaced copyright message with explanation/instruction
    [halconf.h]
2024-09-02 Updated config.h
    This update simply prevents errors in cases where you add Tap Dance while also removing the Tap Dance map on some keymaps
    [config.h]
2024-09-08 Adding switching between Joystick Modes on the Joystick keymap
